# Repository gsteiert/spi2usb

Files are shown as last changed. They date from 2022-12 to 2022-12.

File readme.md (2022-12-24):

# SPI2USB

This is a USB adapter for the EK-10M08E144 MAX 10 Evaluation Kit.  
It adds a micro USB connector by connecting to the SPI connector J11.

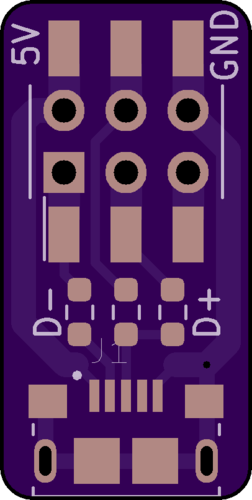
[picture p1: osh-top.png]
top side
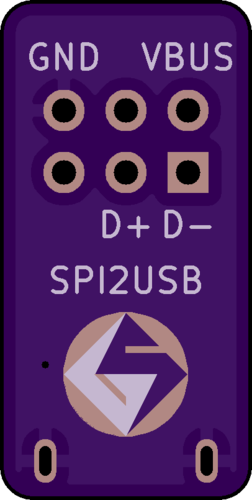
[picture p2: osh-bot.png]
bottom side
 

## Connections

|  USB  |  J11  | 10M08E144 |
| :---: | :---: | :--- |
|  D+ | 3 | 70, DIFFIO_TX_RX_B27P |
|  D- | 1 | 69, DIFFIO_TX_RX_B27N |
|  PU | 4 | 66, DIFFIO_TX_RX_B25N |
|  GND  | 6 | |
|  VBUS | 2 | |

## Schematic

[Schematic](spi2usb-sch.pdf)

## BOM 

 * [Micro USB Connector: 10118193-0001LF](https://www.mouser.com/ProductDetail/649-10118193-0001LF)
 * [2x 24 Ohm 0603 Thick Film Resistor: RC0603FR-0724RL](https://www.mouser.com/ProductDetail/603-RC0603FR-0724RL)
 * [1.5K Ohm 0603 Thick Film Resistor: RC0603FR-7W1K5L](https://www.mouser.com/ProductDetail/603-RC0603FR-7W1K5L)
 * [2x3 SMT Bottom Entry Socket: HLE-103-02-F-DV-BE-TR](https://www.mouser.com/ProductDetail/200-HLE10302FDVBETR) (optional)

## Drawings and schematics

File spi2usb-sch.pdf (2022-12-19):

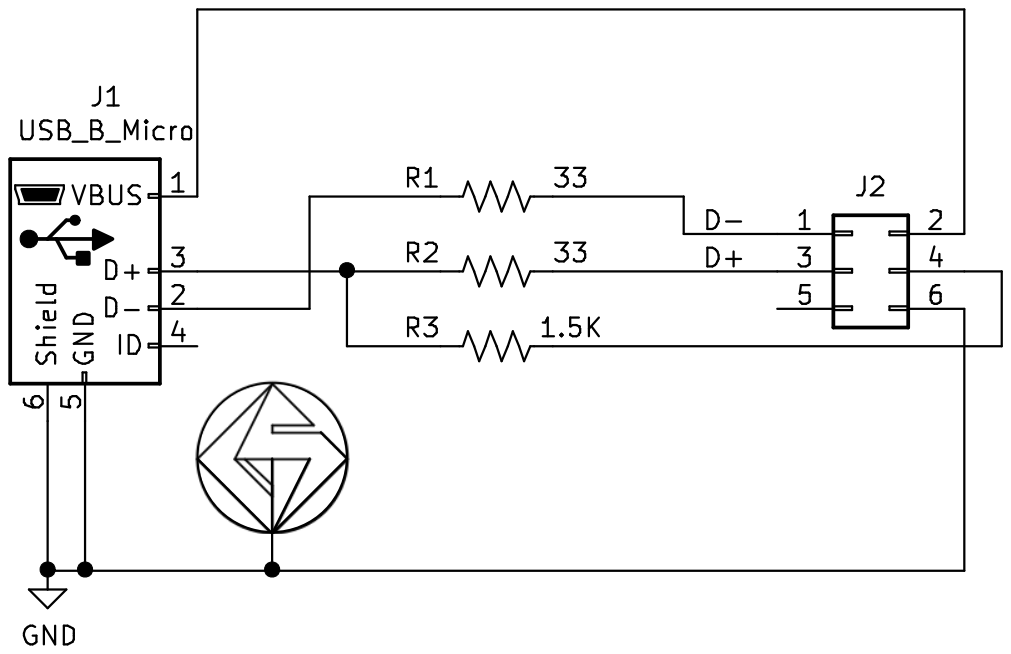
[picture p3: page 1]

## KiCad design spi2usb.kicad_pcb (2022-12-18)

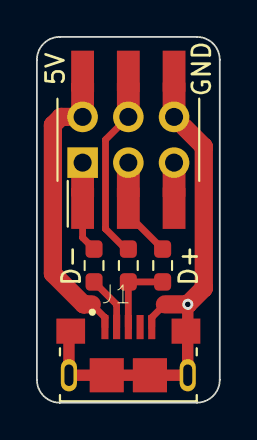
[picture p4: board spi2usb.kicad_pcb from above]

Board: 2 copper layers, 10.2 x 20.3 mm, 6 parts (1 on the bottom side), 7 nets.

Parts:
D+: 33; R_0603_1608Metric_Pad0.98x0.95mm_HandSolder
D-: 33; R_0603_1608Metric_Pad0.98x0.95mm_HandSolder
GS1: GS_logo; gs_logo_200mil
J1: USB_B_Micro; FCI_10118193-0001LF-shield6
J2: Conn_02x03_Odd_Even; HDR_2x03_Dual
R3: 1.5K; R_0603_1608Metric_Pad0.98x0.95mm_HandSolder

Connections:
/D+: D+.1, J2.3
/D-: D-.1, J2.1
GND: GS1.1, J1.5, J1.6, J2.6
unnamed: J1.1, J2.2
unnamed: D-.2, J1.2
unnamed: D+.2, J1.3, R3.2
unnamed: J2.4, R3.1
